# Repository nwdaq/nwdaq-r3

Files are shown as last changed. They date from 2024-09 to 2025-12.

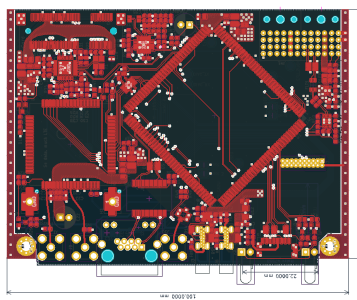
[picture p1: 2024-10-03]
doc/src/figures/nwdaq-r3-sample-board.png

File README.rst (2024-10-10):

======================================
nwDaq-R3 subrack platform
======================================

The nwDaq-R3 is the third revision of a modular subrack platform, designed to accommodate remote data
acquisition and logging devices in the form of plug-in units. Compliant with the IEC 60297-3 standard,
it leverages widely available components from multiple manufacturers and distributors.

This open specification is released under a permissive license, encouraging the development of compatible
devices that can help us better understand and protect our environment. By making it easy to measure and
gather data, we aim to promote a safer and more sustainable world for everyone.

Building
==================

``sphinx-build -b singlehtml doc/ doc/build``

Copying
====================

© 2024 Marek Koža <qyx@krtko.org>

This work is licensed under Creative Commons Attribution-ShareAlike 4.0 International.
To view a copy of this license, visit https://creativecommons.org/licenses/by-sa/4.0/

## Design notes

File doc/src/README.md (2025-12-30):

# The nwDAQ-R3 subrack DAQ platform

nwdaq-r3

## Introduction

The nwDAQ-R3 is the third revision of a subrack platform designed to house remote data acquisition and logging devices
in the form of plug-in units. It is compliant with the IEC 60297-3 standard and utilizes common components that are
widely available from multiple manufacturers and distributors.

For detailed information on the subrack assembly and its components, including dimensions, please refer to the
[mechanical design](mechanical-design.md) section. This section covers topics such as side panels, horizontal rails,
rail positions, subrack sizes and depths, backplane mounting, front panels and blinds for plug-in units, plug-in units
themselves, and backplane connector layouts.

The [electrical design](electrical-design.md) section provides details on the signals on the backplane,
including power rail types, power classes, and redundant communication buses for both low-power, slow and high-speed
data transfer.

To ensure software compatibility, the [communication protocols](protocols.md) section outlines the protocols used on
the ``nwdaq-nbus2`` bus, as well as the ``10Base-T1S`` and ``100Base-T1/1GBase-T1`` buses. Additionally, this section
describes the protocol used for the ``nwdaq-pbus`` bus, which is employed for communicating power resource information.

## State of the document

The current state of the specification is WIP (Work In Progress).

Changes can be tracked in the
[specification GitHub repository](https://github.com/nwdaq/nwdaq-r3), which serves as the normative source of this text.

## Key-word usage

The key words "MUST", "MUST NOT", "REQUIRED", "SHALL", "SHALL NOT",
"SHOULD", "SHOULD NOT", "RECOMMENDED", "NOT RECOMMENDED", "MAY", and
"OPTIONAL" in this document are to be interpreted as described in
BCP 14 [RFC2119] [RFC8174] when, and only when, they appear in all
capitals, as shown here.

## License





This work is licensed under CC BY-SA 4.0. To view a copy of this license,
visit [https://creativecommons.org/licenses/by-sa/4.0/](https://creativecommons.org/licenses/by-sa/4.0/)

© 2025-2026 Marek Koza <marek.koza@nwdaq.com> \
© 2023-2024 Marek Koza <qyx@krtko.org>

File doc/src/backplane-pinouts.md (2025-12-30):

# Backplane connector pinouts

The backplane contains slots for 8 connectors named JM0 to JM7, JM0 being on the bottom. There are
rules regarding the connector usage and future-proofing of the platform:

-	All connector positions are optional from the electrical point of view. Absence of any
	single connector MUST NOT cause any malfunction.
-	Some connector combinations have no meaningful sense. Such combinations SHOULD NOT be used.
	If a slot usage depends on any other slot, it MUST be noted in the specification
	and the reason MUST BE properly explained.
-	A compatible version of the specification MAY add connectors to unused slots
-	Replacing connector in an existing slot or removing a connector slot from the specification
	means introducing an incompatible specification change.

> [!note]
> Add connector dependencies and connector group usage notes. Probably the best place for this
> information is directly in the following subsections.

## JM0

``JM0`` connector provides power and data for simple and low power units usually in the 1-3 power class.
No power or communication redundancy is available if only JM0 is used. Signal placement on the connector
is optimized to allow using PCBs made with simple processes, 2 or 4 layer.

Backplane connector pinout and suggested routing - JM0

``JM0`` backplane connector signal description:

|Signal |Description |
|---|---|
|CD |Card detect. Connect resistor to GND or VBUS_LP. See [card detection](card-detect.md) section. |
|CH |Chassis ground. See `grounding-concept`. |
|GND |Plug-in unit main ground connection. |
|VBUS_LP |Low-power bus connection |
|T1S_P |10Base-T1S bus, positive |
|T1S_N |10Base-T1S bus, negative |
|NBUS_P |First ``nwdaq-nbus2`` bus, positive |
|NBUS_N |First ``nwdaq-nbus2`` bus, negative |
|Reserved |Reserved pins for debug, ID LED, etc. |

## JM1

``JM1`` connector provides a redundant ``VBUS_LP`` power and a redundant ``nwdaq-nbus2`` data communication.
For units with higher data transfer requirements, ``100Base-T1/1GBase-T1`` interface is available.

> [!warning]
> When speaking of redundancy, there is no point in including the ``JM1`` connector without also including
> the ``JM0`` connector. While it may be reasonable to use ``JM1`` alone eg. for a high-speed plug-in
> unit utilizing only the ``100Base-T1`` bus and the second ``VBUS_LP`` bus, it does not work in practice.
> A power sourcing unit may only supply the first ``VBUS_LP`` power bus, leaving such unit unpowered.
> Hence, when ``JM1`` connector is used, ``JM0`` MUST also be used.

Backplane connector pinout and suggested routing - JM1

``JM1`` backplane connector signal description:

|Signal |Description |
|---|---|
|GND |Plug-in unit main ground connection. |
|VBUS_LP |Redundant low-power bus connection |
|SPE_P |Single-pair ethernet 100Base-T1/1GBase-T1 bus, positive |
|SPE_N |Single-pair ethernet 100Base-T1/1GBase-T1 bus, negative |
|NBUS_P |Redundant ``nwdaq-nbus2`` bus, positive |
|NBUS_N |Redundant ``nwdaq-nbus2`` bus, negative |
|Reserved |Reserved pins for USB, etc. |

## JM2

``JM2`` connector carries any application specific differential signals in a star topology. The exact fan-out
is backplane and bus/protocol specific. A few examples of plug-in units with ``JM2`` used for custom
signalling are:

* a main unit or a USB hub unit using the connector to fan-out its USB downstream ports
* an ethernet switch unit connecting individual switch ports to ``JM2`` differential lanes
* a clock distribution unit using ``JM2`` lanes to distribute differential clock to neighboring units

Backplane connector pinout and suggested routing - JM2

``JM2`` backplane connector signal description:

|Signal |Description |
|---|---|
|GND |Ground connection. |
|Lx_P |Lane x, positive |
|Lx_N |Lane x, negative |

## JM7

``JM7`` connector provides a high power ``VBUS_HP`` bus capable of delivering maximum of ``10 A`` at a ``28 V``
nominal voltage (``26.4 V`` centered when the power sources/sinks are in regulation).

Additionally, it provides a separate chassis ground connection, a separate card detect input/output
and a ``nwdaq-pbus`` single-wire bus to communicate all power sources/sinks on the backplane.

> [!tip]
> A plug-in unit MAY use ``JM7`` connector alone without any other connectors if the sole purpose of the
> unit is sinking or sourcing power. Hot-plug is handled with the dedicated ``CD`` pin and the communication goes
> only through the ``nwdaq-pbus`` bus.

> [!tip]
> If a power sinking plug-in unit is capable of operating with various power levels, it may contain both ``JM0/JM1``
> and ``JM7`` connectors and use whatever is available, or, use ``JM7`` when available to sink higher power levels
> while fall-backing to ``JM0/JM1`` when only ``VBUS_LP`` is available.

Backplane connector pinout and suggested routing - JM7

``JM7`` backplane connector signal description:

|Signal |Description |
|---|---|
|CD |Card detect. Connect resistor to GND or VBUS_LP. See [card detection](card-detect.md) section. |
|CH |Chassis ground. See [grounding concept](grounding.md). |
|GND |Plug-in unit main ground connection. |
|VBUS_HP |High-power bus connection |

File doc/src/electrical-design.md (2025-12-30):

# Electrical design

## Overall concept

Plug-in units are interconnected with a backplane mounted on the rear horizontal rails within the subrack.
Power to the backplane is provided using bidirectional/source units from their respective front panels.
Data communication and any field connections are only done on plug-in unit front panels.

> [!note]
> Describe requirements and missing parts of the specification for:
> - power filtering
> - maximum power levels
> - hot-plug/unplug management

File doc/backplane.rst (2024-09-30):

============================
Backplane
============================

Power concept
======================

The backplane has the function to distribute power to all units within a single subrack. Dynamic range of the power
required by the units is very wide - from microwatts to 200 W. For the purpose of unit classification, a range
of power classes is established. It can be used as a guide for selecting the right unit for the particular job.

======= =============== =============== ================================================================================
Class   Average power   Peak power      Examples
======= =============== =============== ================================================================================
``1``   0-1 mW          100 mW          Extremely low power optimized devices or devices in standby
                                        during normal use. For primary battery powered applications. LP bus connection
                                        only.
``2``   1-100 mW        1 W             Middle power devices optimized for low power consumption. The elevated power
                                        usage is usually caused by more complex data logging, fast sampling,
                                        RF usage, etc. Low power main units are usually Class 2.
``3``   100 mW - 2 W    5 W             Middle power devices, usually multi-radio interface units, Linux-capable
                                        main units, data storage units.
``4``   2-10 W          20 W            High power specialized devices.
``4b``                  +-20 W          Middle power bidirectional units intended for providing power, battery backup
                                        units, solar input units.
``4h``  2-10 W          20 W            High power units connected to the high power bus, 20 W maximum.
                                        various power sinks for isolated power sources, bus power sources, etc.
                                        Sink only allowing a simple bus connection.
``4hb``                 +-20 W          Same as 4b, power is provided over the high power bus. Bidirectional power flow.
``5hb``                 +-110 W (4 A)   High power bidirectional unit.
``6hb``                 +-280 W (10 A)  High power bidirectional unit usually with specific cooling requirements.
======= =============== =============== ================================================================================

Low-power bus connected sink-only units (class 1-4)
-----------------------------------------------------

Units with power class ``1`` to ``4`` are sink-only units connected only to the low power bus. The low power bus
provides power with a 5 V nominal voltage and current levels of 2 A average and 4 A peak. The electronics used to
connect to the power bus varies depending on the class. In the simplest case (class ``1``) no specific handling of
hot-plug events and inrush current is needed, whereas class ``4`` requires more delicate PCB design to handle high
currents, hot-plug controller and power switch, inrush current limiter, noise filtering, etc.

Low-power bus connected bidirectional units
------------------------------------------------

For systems utilizing low-power bus only, class ``4b`` provides means to source power to the backplane for low power
applications. A system with a class ``4b`` source only can usually provide power for multiple class ``1``-``3`` units
and one class ``4`` unit.

High-power bus connected sink-only units (class ``4h``)
-------------------------------------------------------

Proper hot-plug management is mandatory. Units are connected to high-power bus only.

High-power bus connected bidirectional units
-------------------------------------------------

Any other high power classes (``4hb``, ``5hb`` and ``6hb``) require advanced electronic for hit-plug management, power
bus protection, unit protection itself, advanced power filtering, advanced high power PCB design, etc. Bidirectional
power flow capability is mandatory.

These units are typically used to power the whole measurement/DAQ system:

- battery packs/units
- photovoltaic power input units
- AC power input units
- external power source/sink device connection using nwDaq p-bus.

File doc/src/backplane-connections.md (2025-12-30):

# Backplane connections

The backplane provides redundant low power rails, a high power rail, redundant ``nwdaq-nbus2`` communication
buses, ``nwdaq-pbus`` power resource communication bus, ``10Base-T1S`` multidrop ethernet bus and
``100Base-T1/1GBase-T1`` point-to-point links. With the exception of the last one, all interconnections are using
the bus topology. Point-to-point ethernet links use the star topology, more on that in the corresponding section.
There are no external connections going to the backplane except connections allowing backplane stacking.

As a result, ``nwdaq-r3`` platform backplane can be fully passive for its essential purpose.
There are no mandatory components on the backplane except:

- ``nwdaq-nbus2`` bus termination (both ends)
- ``10Base-T1S`` bus termination (both ends)
- ``nwdaq-pbus`` pull-up resistor

All connections are organized into 8 backplane connectors placed in slots with designations JM0 to JM7. The following
table lists all connections within the particular backplane connector.

|Connector  |Name |Description |
|---|---|---|
|JM0 |Basic power and data |Contains the required minimum for a unit. It carries ``VBUS_LP`` low power bus, ``nwdaq-nbus2`` communication bus, ``10Base-T1S`` ethernet bus, card detect input/output, chassis ground connection. |
|JM1 |Redundant power and data |This is a redundancy and data speed extension. It carries an independent ``VBUS_LP2`` low power bus, an independent redundant ``nwdaq-nbus2`` communication bus and a 100Base-T1/1GBase-T1 point-to-point ethernet link (the actual connected target depends on the backplane design). |
|JM2 |App specific, star |Application-specific fanout of 10 differential lanes, connections to other units are dictated by the backplane design. See JM2 addendums for commonly used connections. |
|JM3 |Reserved | |
|JM4 |Reserved | |
|JM5 |Reserved | |
|JM6 |Reserved | |
|JM7 |High power bus |Carries signals and buses for high power units. ``VBUS_HP`` high power bus capable of delivering ``10 A`` at ``28.8 V`` maximum, ``nwdaq-pbus`` power resource bus, card detect input/output and a chassis ground connection. |

The following subsections briefly describe all available power and data buses.

## ``nwdaq-nbus2`` data bus

``nwdaq-nbus2`` is designed with the following constraints and requirements in mind:

- very low power during the idle state with commonly available CAN bus transceivers
- moderate speeds achievable (1-4 mbit/s on the backplane, 250 kbit/s nominally over long runs)
- request/response (unicast) or multicast
- wired-OR operation to avoid power peaks during collisions
- packet-switched
- native encryption using pre-shared keys providing basic security on the data link layer
- packet size up to 1024 B (this limit is TBD)

On the **physical layer** (L1) level, the bus uses ``CAN 2.0b`` signalling as specified in ISO 11898-2.
Common CAN transceivers can be used to access the ``nwdaq-nbus2`` bus. CAN MAC is not used.

Detailed description of the ``nwdaq-nbus2`` protocol on the MAC and higher levels can be found in the
corresponding section [nbus2 data link layert](nbus2-dll.md).

> [!note]
> There is also a legacy possibility of tunneling ``nqdaq-nbus2`` over a real ``CAN 2.0b`` bus.
> This concept is not part of this specification as it is no longer recommended nor used.
> ``CAN 2.0b`` has a maximum bus length limit for the specified bitrate (ACK bit) and also a
> bitrate limit. Newer CAN bus versions have in-force patents as of 2025.

## ``VBUS_LP`` low power bus (main and redundant)

``VBUS_LP`` buses carry ``5 V`` power to plug-in units, ``4 A`` maximum per unit. The total aggregated backplane
current is limited to ``8 A``. The bus uses its voltage to communicate the currently available amount of power
in total. It is called ``power-availability``, where ``pa--`` state means the shortage is
long lasting, all backup resources are deprived and power failure is imminent, ``pa-`` is the common state when eg.
running on batteries, ``pa0`` means the energy sinking/sourcing is in balance, ``pa+`` means there is a surplus of
energy available (eg. to charge backup batteries) but the amount of energy is limited, ``pa++`` means there is a
power source with virtually infinite capacity (an AC connection for example).

``pa0`` is always at the nominal bus voltage level, ``5 V`` for ``VBUS_LP``. ``pa-`` and ``pa--`` are 5% and 10% less
tha nominal, respectively. ``pa+`` and ``pa++`` are 5% and 10% more than nominal. There is a +-2.5% tolerance on the
voltage levels, that is, ``pa-`` being -7.5% to -2.5% lower than the nominal voltage, for example.

Voltage levels lower than 12.5% less than the nominal voltage are considered bus undervoltage and must trigger
plug-in units ``UVLO`` protection disconnecting the units from the bus.

Voltage levels higher than nominal + 12.5% are considered overvoltage and all units must deal with it individually by
cutting the bus off (an ``OVP`` protection).

Additionally, all sinking units must limit their current sink to the value specified in the corresponding unit
datasheet, no more than ``4 A``, which is the maximum current possible for the ``VBUS_LP`` bus. This limit protects
the backplane connector and wiring and maintains availability of the bus power in case of a misbehaving unit. The
same applies to sourcing units which are required to source power in a CC/CV manner, limiting the current to ``4 A``
per ``VBUS_LP``. This protects the unit itself from possible bus shorts.

Graphical representation of power availability levels for ``VBUS_LP`` and ``VBUS_HP``

> [!note]
> For practical reasons, ``VBUS_LP`` voltage levels are compatible with USB 2.0 and USB 3.0 voltages and it can
> be interfaced with them using minimum amount of components. The power availability feature together
> with the sinking/sourcing regulation on individual units help sink the power without overloading the USB port.

## High power bus ``VBUS_HP``

``VBUS_HP`` bus provide the same functionality as ``VBUS_LP``, with higher voltage levels. The nominal ``VBUS_HP``
voltage is ``26.4 V``, power availability levels remain the same. The bus voltage is usually referred to as ``28 V``
despite not being strictly true. Maximum current per unit is ``4 A`` for standard units, yielding ``105 W`` of
available power. When appropriate measures are taken on the unit, the maximum current per unit can be ``10 A``
(``264 W`` of power), if the backplane allows that.

The total current permissible to be carried over the backplane is ``40 A`` and is limited by the
backplane design and thermal management. Refer to the backplane datasheet for the exact figure.

> [!note]
> Again, for practical reasons, voltage levels on ``VBUS_HP`` are compatible with 12-cell lead-acid batteries
> and with 8-cell LiFePO4 battery packs. Under specific circumstances and using appropriate protections,
> such battery packs can be connected to the ``VBUS_HP`` bus directly without any further regulation.

> [!caution]
> ``VBUS_HP`` carries high currents and current limiting and inrush current limiting is mandatory.
> See the corresponding section on handling hotplug events.

## Ethernet data connection over 10Base-T1S

## Ethernet data connection over 100Base-T1/1GBase-T1

## Application specific differential lanes

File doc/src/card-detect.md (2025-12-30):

# Card insertion detection

> [!note]
> This section is WIP

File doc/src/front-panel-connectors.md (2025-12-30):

# Recommended front panel connectors

> [!note]
> This section is WIP

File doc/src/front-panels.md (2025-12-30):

## Plug-in unit front panels

The cceptable thickness of the front panel is 2, 2.5 and 3 mm. Width of the front panel is calculated as
``n * 20.32 - 0.30 mm``, where ``n`` represents the width of the unit in modules with each module being ``20.32 mm``
wide. For a 1-module wide plug-in unit, the nominal width is ``20.02 mm``. The height of a 3U front panel is
``128.4 mm``.

Front panels contain two holes for attaching to a PCB, they are horizontally centered to the second HP from the left.
Vertical distance of the holes is ``99.00 mm``, diameter is ``2.7 mm`` and they are vertically centered.

Near the bottom PCB holder hole, there are multiple helper holes to aid in the alignment of the front bracket/holder.
These holes are spaced ``5.08 mm`` apart, typically one hole to the left and two holes to the right of the PCB holder
hole. Please refer to the figure below for further clarification.

Front panels are secured to the subrack front rails using two ``M2.5`` screws for 1 module wide units and four
``M2.5`` for units that are 2 modules or wider. The attachment holes are horizontally centered in the second HP from
the left (and second HP from the right for 2-module and wider units). The holes are vertically centered and their
vertical distance is ``122.5 mm``.

Front panel for 1 module wide plug-in unit

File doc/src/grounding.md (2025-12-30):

# Grounding concept

> [!note]
> This section is WIP

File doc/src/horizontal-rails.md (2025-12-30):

## Horizontal rail position and side panel dimensions

The *platform* uses only 3U high subracks. Height of the subrack assembly is ``132.35 mm``.

Width of the subrack is variable. The following rules must be respected:

- one horizontal pitch unit ``HP`` is ``5.08 mm`` wide
- unit width is exactly ``4 HP``, yielding ``20.32 mm``. We call it a *module*.
- the first ``HP`` starts ``2.54 mm`` (``0.5 HP``) from the left
- there is an additional ``0.5 HP`` at the end of the rail

Front horizontal rails with rack-mountable side panels (drawing not to scale)

The resulting horizontal rail length is ``(n * 20.32 + 5.08) mm``, ``n`` being the count of modules
in the subrack assembly. Table below lists some common combinations and rail lengths.

|Modules |Width in HP |Rail length in mm |Comment |
|---|---|---|---|
|10 |41 |208.28 |Size for 10" racks |
|21 |85 |431.80 |Size for 19" racks |

Side view of the subrack with the corresponding dimensions is pictured below.

Side panel with horizontal rails attached, side view

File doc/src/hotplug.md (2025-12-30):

# Hot-plug requirements

All platform components MUST handle hot-plug events in the described fashion. Failing to do so may result
in unpexpected behaviour, premature component failure or degradation. Connector contacts are extremely
susceptible to failure when unrush currents are not managed properly.

``VBUS_LP`` and ``VBUS_HP`` have slightly different requirements, these are described in their individual
sections right after the common hot-plug introduction.

## Definition of cold/hot/surprise plugging and unplugging of plug-in units

**Plugging** in a plug-in unit into a backplane means inserting the unit slowly into the card guide
groove and pushing it towards the backplane until a contact is made. During the process, an intermittent
reconnections may happen as the operator movement is not steady and perfect. After the unit is fully
inserted, it is secured with two or more front panel bolts.

**Unplugging** a plugin unit is a reverse process. First, the securing bolts are released and the unit is
pulled from the backplane afterwards. It is being pulled until it is completely off the card guide grooves.
During the instant of pulling the unit from the backplane, connectors may be intermittently reconnected as
a result of eg. multiple pull attempts.

Both events may be done in several platform states.

**Cold** plug or unplug means a plug-in unit is plugged-in or plugged-out to/from a system without any power
or communication on the backplane. This includes situations when there are individual plug-in units
still powered (eg. a power supply or a battery backup unit) but not sourcing any current into the backplane
ower rails and the bacplane is unpowered.

A system MAY BE commanded into a cold state externally by eg.pressing a button on a power supply or instructing
a programmable power supply to turn off remotely.

**Hot** plug/unplug means the unit is inserted or pulled out from a live system, when the backplane power rails are
powered and possibly a communication is ongoing on one or multiple data busses. The system MUST BE instructed
and prepared for hot-plug or hot-unplug event by suitable means, eg. by pressing a button or instructing
a main plug-in unit programatically. The system MUST allow hot-plug or hot-unplug in a timely manner and it
SHOULD signal the user when it is ready.

**Surprise** plug/unplug means the system is not prepared for the action in any way and the user is allowed
to insert or pull out a plug-in unit any time. This action MUST NOT cause any power supply instability or
any communication failure except when the communication was ongoing with the unit being pulled out.

## General requirements

**Stacking** plug-in units MAY support hot plugging or surprise plugging but are generally not required to. A stacking
plug-in unit is an unit which bridges backplane connections in a suitable way to external cabling, which can be
bridged back into another backplane with a second stacking plug-in unit. As connecting two live backplanes
together is a complex task, this functionality is not required. Stack assembly or disassembly MUST NOT be done
if at least one of the backplanes is live (powered) unless it is allowed explicitly by the stacking unit specification.

**Power sourcing units**, whether sourcing power to ``VBUS_LP`` or ``VBUS_HP``, MUST regulate the output in a constant
voltage, constant current manner, thus limiting the output current to the specified value. Moreover, they must sense
the ``CD`` pin on the ``JM0`` or ``JM7`` backplane connector to determine when they are fully inserted. Units SHOULD
debounce the ``CD`` input and wait at least one second after the ``CD`` input is stable, before applying any power
to the bacplane power rails.

Any unit which **sinks** power must use a suitable over-current protection on all power buses it uses. If the maximum
current draw of the unit is less than ``100 mA`` under all circumstances, it MAY use a polyfuse (PPTC) as
an over-current protection and a ``5 V`` TVS diode MAY be used as a over-voltage protection.
If the input capacitance of the unit power bus input is less than ``100 uF``,
a simple high-side MOSFET with a gate capacitor can be used for inrush current limiting and delayed turn-on.
If the input capacitance is ``1 uF`` or less, inrush current limiting is not mandatory. This capacitance includes
the input filter capacitance, if any.

In all other circumstances, a proper integrated circuit managing UVLO (under-voltage lockout), OVP (over-voltage
protection), inrush current limiting, OCP (over-current protection) and delayed turn-on SHOULD be used.
Refer to the [parts cross reference](parts.md) for suggestions.

> [!caution]
> With the simplest possible solution, no UVLO is provided. The unit MUST handle under-voltage by any other
> suitable method, eg. a UVLO input of the downstream voltage regulator or a brown-out detector on the MCU.
> The unit MUST go into a low power/reset state when under-voltage occurs.

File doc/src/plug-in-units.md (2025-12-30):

## Plug-in unit PCB dimensions

A single plug-in unit comprises of at least these components:

- front panel with the specified design
- front panel bracket/holder to assist with pullting the unit out of the subrack
- two PCB holders
- one or more backplane connectors on the back
- PCB

For more elaborate designs there may be more components in a single unit, eg. multiple PCB holders when more than one
PCB is used, helper connectors, PCB cover, etc.

The basic dimensions of a plug-in unit are depicted below:

Dimensions of a plug-in unit main PCB

### PCB dimensions

The PCB SHOULD have rectangular shape, MUST be ``100 mm`` wide and SHOULD be ``73 mm`` long.
PCB to front panel gap SHOULD be ``2.54 mm`` and PCB to backplane distance SHOULD be ``12.5 mm``.
This distance is optimized for *TE Metral* connectors.

> [!tip]
> Under some circumstances it is possible to extend the PCB up to ``2.34 mm`` to the front panel, removing the
> gap and leaving some headroom of ``0.2 mm`` for PCB and front panel tolerances. The complete PCB length will
> be ``75.34 mm`` in this case (``75.0 mm`` being more common).
>
> This helps to accomodate PCB connectors which are mounted too close to the front panel.

> [!warning]
> Observe isolation clearance between the PCB and the front panel.

### PCB clearances

On both sides of the PCB, there is a space reserved for card guide grooves, which MOST NOT contain any
components on front and back PCB sides. The reserved space MUST be at least ``3 mm`` wide and it is recommended
to place a mask-free exposed copper pour at least on the outer ``2 mm`` of the PCB. If an exposed copper pour
is used, it MUST be connected to the chassis ground (``CH`` pin on the ``JM0`` and ``JM7`` backplane connector).

### PCB mounting holes

There are two mounting holes on the PCB which are used to fasten front panel angle brackets. These holes MUST
have a diameter of ``2.7 mm`` to accomodate ``M2.5`` bolts. Holes are positioned ``6.11 mm`` from the front panel
and are spaced ``88.90 mm`` apart, centered on the PCB. Refer to the figure above for hole positions.

### PCB components maximum height

Considering the PCB thickness of ``1.60 mm``, PCB surface to the module boundary/``HP`` distance is:

* ``2.50 mm`` on the bottom side of the PCB
* ``16.20 mm`` on the front side of the PCB

There MUST be at least ``0.40 mm`` distance between components and the module/``HP`` boundary, which means
the maximum allowable component height is:

* ``2.10 mm`` for bottom-side components
* ``15.80 mm`` for front-side components

> [!caution]
> If the PCB requires a defined minimum electrical clearance, it MUST consider the neighboring plug-in unit to fully
> utilize its available space.

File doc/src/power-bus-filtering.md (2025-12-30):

# Power bus filtering

> [!note]
> Power bus filtering section is WIP

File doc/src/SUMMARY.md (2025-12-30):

# Summary

[Introduction](README.md)

# Specification

## Mechanical design

- [Mechanical design](mechanical-design.md)
	- [Horizontal rail position and side panel dimensions](horizontal-rails.md)
	- [Plug-in unit front panels](front-panels.md)
	- [Plug-in unit PCB dimensions](plug-in-units.md)
- [Electrical design](electrical-design.md)
	- [Backplane connections](backplane-connections.md)
	- [Backplane connector pinouts](backplane-pinouts.md)
	- [Power bus filtering requirements](power-bus-filtering.md)
	- [Hot-plug requirements](hotplug.md)
	- [Card insertion detection](card-detect.md)
	- [Grounding concept](grounding.md)
- [Communication protocols](protocols.md)
	- [nbus2 data link layer](nbus2-dll.md)
- [Application information](application.md)
	- [Front panel connector recommendations](front-panel-connectors.md)

- [Parts and component cross reference](parts.md)
- [List of abbreviations](abbreviations.md)
- [Contributing and feedback](contributing.md)

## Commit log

2024-09-30 docs: Add backplane power concept
2024-09-30 docs: Add power class description, group similar classes
2024-10-03 chore: Add Sphinx configuration and static resources
    [horizontal-rails.kicad_pcb]
2024-10-04 docs: Add side view drawing
    [horizontal-rails.kicad_pcb, side_view.kicad_pcb]
2024-10-09 docs: Add a power-availability figure
2024-10-09 docs: Add figure/drawing sources in KiCad
    [backplane-connector-pinout-jm0.kicad_pcb, backplane-connector-pinout-jm1.kicad_pcb, backplane-connector-pinout-jm2.kicad_pcb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]
